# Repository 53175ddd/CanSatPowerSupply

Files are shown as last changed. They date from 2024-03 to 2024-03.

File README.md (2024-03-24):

# CanSatPowerSupply

缶サット用自作マイコンボード向け電源ユニット  
CR2032 または LIR2032 が使用できます  
LIR2032 使用時，外部電源入力に 5V を供給することで 10mA 定電流ダイオードと 3.9V 定電圧ダイオードでの簡易 CCCV 充電が可能です

また，電源電圧監視用 ADC 入力が可能で，GPIO32 ~ GPIO35 を入力として選択可能です

# 部品表

| 部品番号 | 部品名 | 秋月 |
|----|----|----|
| BT1 | バッテリホルダ | <https://akizukidenshi.com/catalog/g/g111348/> |
| C1 ~ C3 | 1uF 0603-1608M | <https://akizukidenshi.com/catalog/g/g114526/> |
| C4 | 10uF 0603-1608M | <https://akizukidenshi.com/catalog/g/g113161/> |
| D1, D2 | 1N4148 | <https://akizukidenshi.com/catalog/g/g100941/> |
| D3 | 定電流ダイオード 10mA | <https://akizukidenshi.com/catalog/g/g100185/> |
| D4 | 定電圧ダイオード 3.9V | <https://akizukidenshi.com/catalog/g/g108710/> |
| J1 ~ J3 | 分割ロングピンソケット | <https://akizukidenshi.com/catalog/g/g105779/> |
| SW1 | SPDT スイッチ | <https://akizukidenshi.com/catalog/g/g115703/> |
| U1 | LTC3245 | <https://akizukidenshi.com/catalog/g/g108177/> |

# ギャラリー

部品実装イメージ

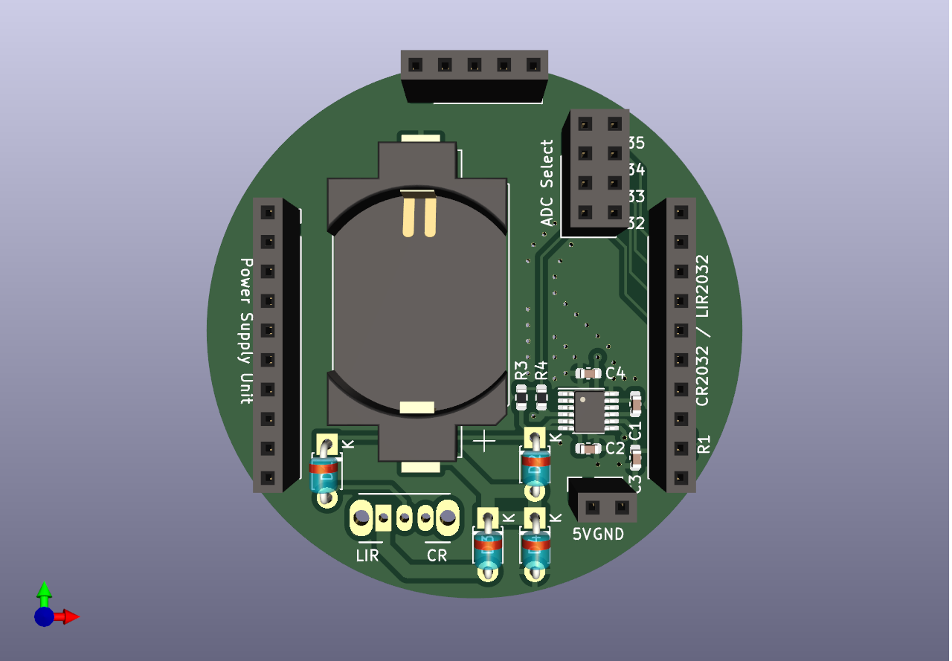
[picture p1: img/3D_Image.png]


回路図

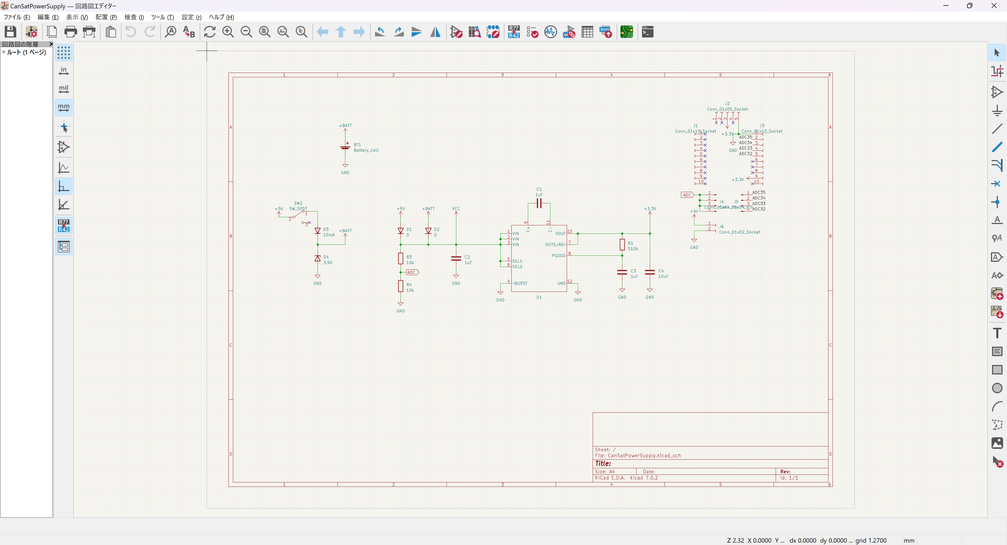
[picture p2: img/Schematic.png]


CAD イメージ

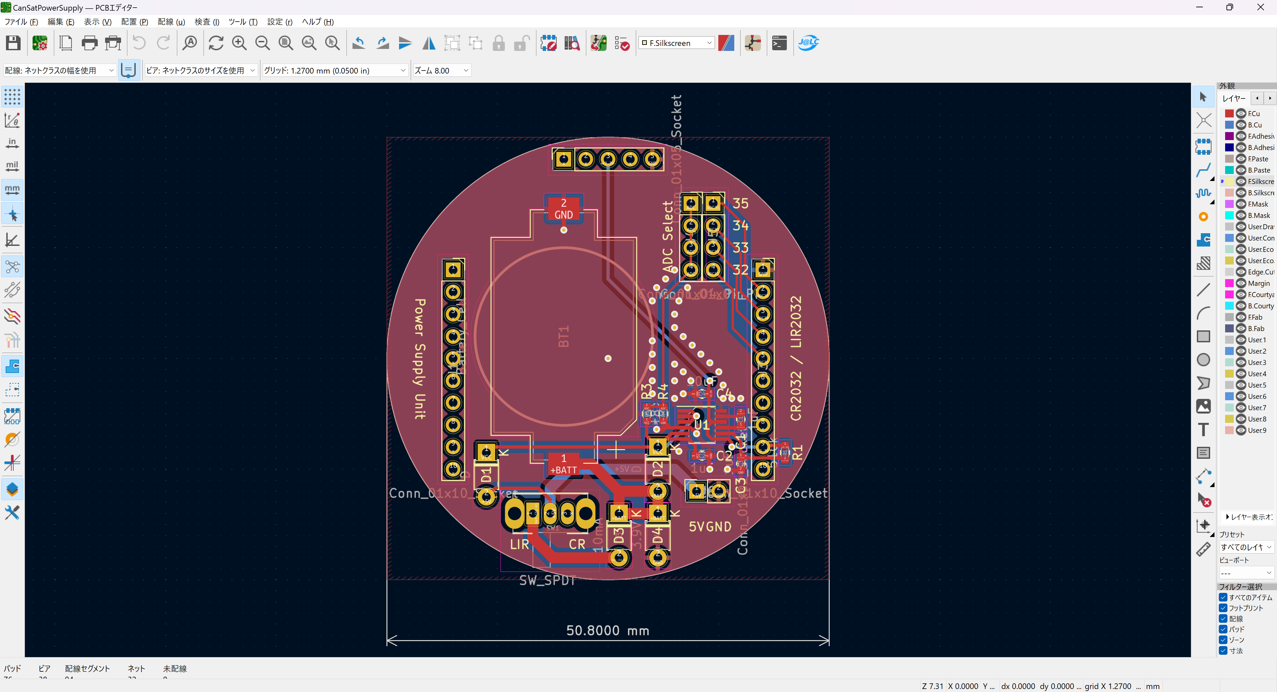
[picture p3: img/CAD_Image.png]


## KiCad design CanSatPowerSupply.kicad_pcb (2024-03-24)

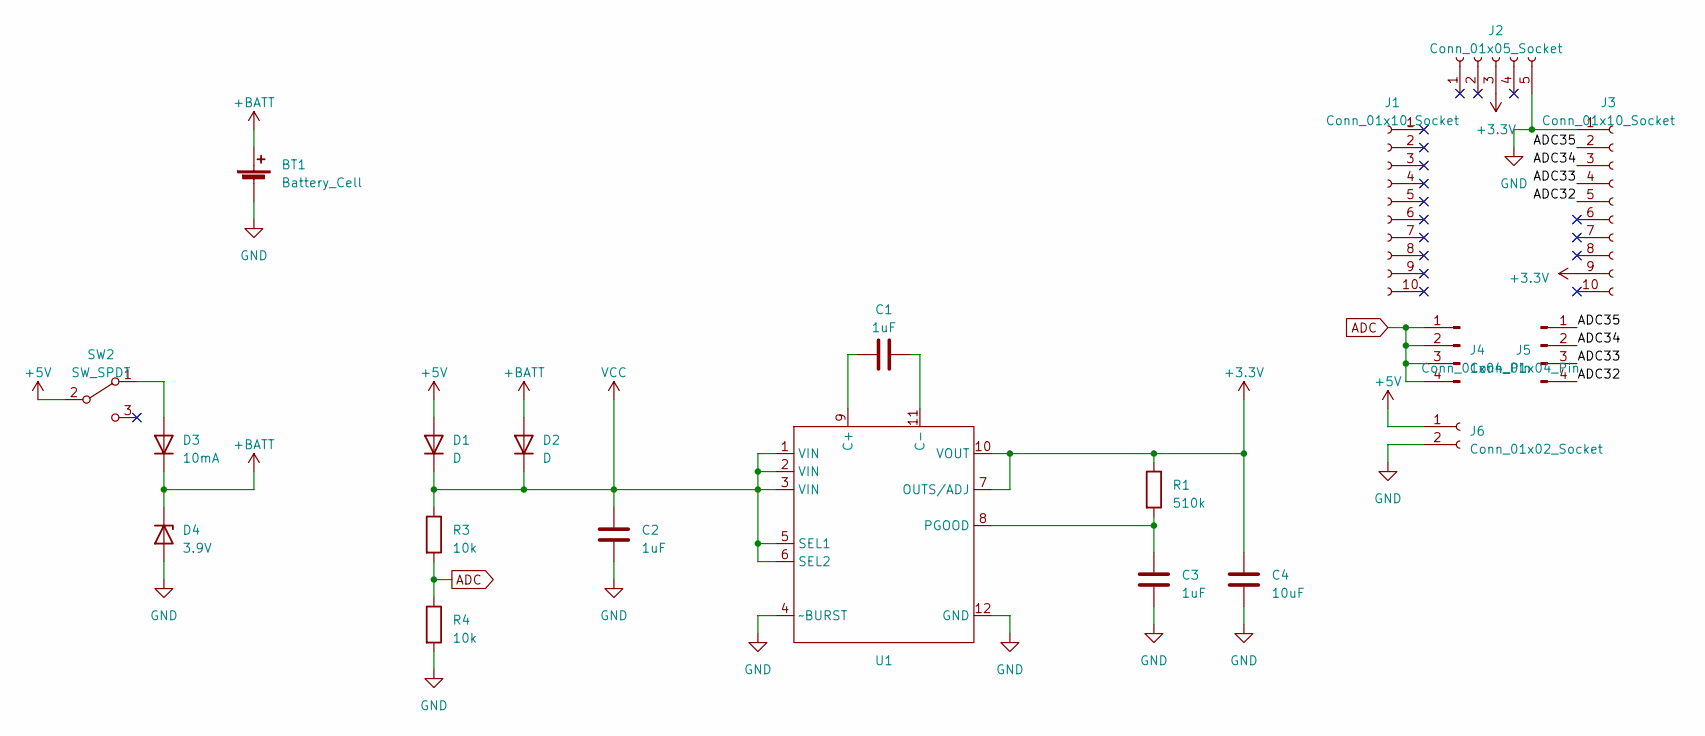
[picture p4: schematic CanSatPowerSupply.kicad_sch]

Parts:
BT1: Battery_Cell; BatteryHolder_Keystone_1060_1x2032
C1, C2, C3: 1uF; C_0603_1608Metric
C4: 10uF; C_0603_1608Metric
D1, D2: D; D_T-1_P5.08mm_Horizontal
D3: 10mA; D_T-1_P5.08mm_Horizontal
D4: 3.9V; D_T-1_P5.08mm_Horizontal
J1, J3: Conn_01x10_Socket; PinSocket_1x10_P2.54mm_Vertical
J2: Conn_01x05_Socket; PinSocket_1x05_P2.54mm_Vertical
J4, J5: Conn_01x04_Pin; PinSocket_1x04_P2.54mm_Vertical
J6: Conn_01x02_Socket; PinSocket_1x02_P2.54mm_Vertical
R1: 510k; R_0603_1608Metric
R3, R4: 10k; R_0603_1608Metric
SW2: SW_SPDT; SW_CuK_OS102011MA1QN1_SPDT_Angled
U1: MSOP-12_3x4mm_P0.65mm

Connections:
+3.3V: C4.1, J2.3, J3.9, R1.1, U1.7 (OUTS/ADJ), U1.10 (VOUT)
+5V: D1.2 (A), J6.1, SW2.2 (B); also elsewhere on the board
+BATT: BT1.1 (+), D2.2 (A), D3.1 (K), D4.1 (K)
/ADC32: J3.5, J5.4
/ADC33: J3.4, J5.3
/ADC34: J3.3, J5.2
/ADC35: J3.2, J5.1
ADC: J4.1, J4.2, J4.3, J4.4, R3.2, R4.1
GND: BT1.2 (-), C2.2, C3.2, C4.2, D4.2 (A), J2.5, J3.1, J6.2, R4.2, U1.4 (~BURST), U1.12 (GND)
unnamed 9: D3.2 (A), SW2.1 (A); also elsewhere on the board
unnamed: C1.1, U1.9 (C+)
unnamed: C1.2, U1.11 (C-)
unnamed: C3.1, R1.2, U1.8 (PGOOD)
VCC: C2.1, D1.1 (K), D2.1 (K), R3.1, U1.1 (VIN), U1.2 (VIN), U1.3 (VIN), U1.5 (SEL1), U1.6 (SEL2)

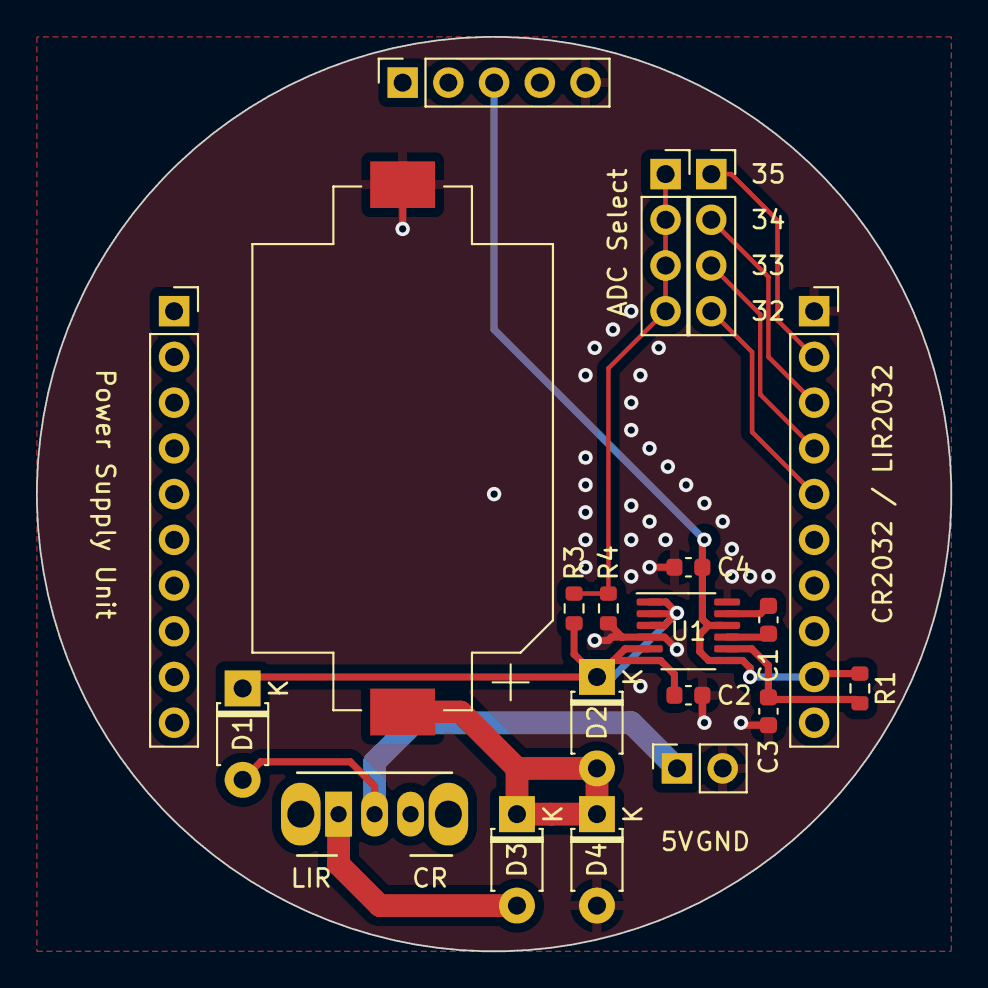
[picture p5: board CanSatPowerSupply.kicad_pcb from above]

Board: 2 copper layers, 50.8 x 50.8 mm, 20 parts (0 on the bottom side), 14 nets.

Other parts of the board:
SW1: SW_SPDT; SW_CuK_OS102011MA1QN1_SPDT_Angled

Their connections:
+5V: SW1.2 (B); also elsewhere on the board
unnamed 9: SW1.1 (A); also elsewhere on the board

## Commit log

2024-03-24 説明書き追加
2024-03-24 体裁調整
2024-03-24 部品表追記
